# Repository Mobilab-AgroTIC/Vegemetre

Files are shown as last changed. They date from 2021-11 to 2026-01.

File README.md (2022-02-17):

# Vegemetre

Le vegemetre permet de mesurer un indice tel que le NDVI pour observer l'expression photosynthétique des plantes. Il mesure 18 longueurs d'ondes allant de 350nm à 950nm. 
Toutes les données sont stockées sur une carte SD.

Ce repository contient

    le code Arduino
    un tutoriel d'utilisation du boitier

# Liste du matériel 
- Un [Arduino Uno Rev 3](https://www.amazon.fr/Arduino-A000066-M%C3%A9moire-flash-32/dp/B008GRTSV6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)
- Un [cable USB type B](https://www.amazon.fr/MYAMIA-Alimentation-Transmission-Donn%C3%A9es-Arduino/dp/B07H23N214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) parfois inclu avec l'arduino
- Un shield LCD comme le [VMA203](https://www.velleman.eu/products/view/?country=be&lang=fr&id=435510)
- Un capteur [AS7265x](https://www.sparkfun.com/products/15050)
- La connectique pour connecter le capteur : 
    - Un [cable qwiic](https://www.sparkfun.com/products/14427)
    - Un [shield qwiic](https://www.sparkfun.com/products/14352)
- Un lecteur de carte SD du type [AZDelivery](https://www.amazon.fr/azdelivery-Reader-M%C3%A9moire-Memory-Arduino/dp/B077MCR2RC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)
- Une [carte micro SD](https://www.amazon.fr/QUMOX-Micro-Carte-M%C3%A9moire-Classe/dp/B07F81QTPP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) classique (pas besoin d'une grosse carte de nouvelle génération. Les cartes de 64Go ne sont pas supportées)

# Montage du système
Le plus délicat est le soudage du support de carte SD sur le shield qwiic.
Détails à venir

# Installation du code

Un guide d'utilisation de ce capteur est donné par [Sparkfun](https://learn.sparkfun.com/tutorials/spectral-triad-as7265x-hookup-guide/all)

Il est nécessaire de télécharger [cette librairie](https://github.com/sparkfun/SparkFun_AS7265x_Arduino_Library/archive/main.zip) pour faire fonctionner le capteur. Telecharger le zip, puis dans le logiciel Arduino, cliquez sur *Croquis > Inclure une bibliothèque > Ajouter la bibliothèque ZIP*, puis selectionner le .zip téléchargé


Le code est disponible sur ce github. Il faut le flasher sur la carte : après avoir branché l'arduino, il faut aller dans *Outils > ports >* Choisir l'arduino
puis cliquer sur le bouton *téléverser* :



#Utilisation du végémetre
La notice d'utilisation est à la racine du github

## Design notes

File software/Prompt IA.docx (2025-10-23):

Fais moi un code pour une arduino UNO, branché avec :

- Un shield LCD de DFROBOT
- Une SD card reader (branché en CS=2)
- Un capteur AS7265x, branché en I2C. Il prend 18 longueurs d’ondes :

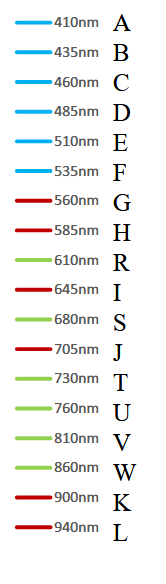
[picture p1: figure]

Le principe est de faire l’acquisition de données spectrales avec le capteur. On veut les stocker sur carte SD.

Quand on allume l’Arduino :

1. On Affiche au milieu « Vegemetre » puis sur la ligne du bas « AgroTIC »
2. On vérifie qu’on a bien le capteur, qu’il répond. Si oui, on envoie Capteur OK (sinon, Capteur KO)
3. Si le capteur est OK, on vérifie qu’on peut bien lire la carte SD. Si non, on envoie « SD Absente. Select=continue ».
4. Si la carte SD est détéctée, on arrive sur un écran où on peut choisir la date au format MM/JJ. Un curseur permet de savoir quel champ on modifie (les 2 M et les 2J). Le 1er M ne peut etre que 0 ou 1. Le 1er J ne peut etre que 0, 1, 2, 3. En appuyant sur select, un fichier MM-JJ.txt est créé avec l’entete :
  a. ID,TempC,LED,NDVI,410nm-A,435nm-B,460nm-C,485nm-D,510nm-E,535nm-F,560nm-G,585nm-H,610nm-R,645nm-I,680nm-S,705nm-J,730nm-T,760nm-U,810nm-V,860nm-W,900nm-K,940nm-L
5. Après le choix du fichier, (ou bien si on a cliqué sur « select=continue » car pas de carte SD, cf point 3) on peut choisir un mode « ponctuel » ou « auto ».
  a. Le mode ponctuel permet de faire de l’acquisition en appuyant sur un bouton Right, et Select pour le sauver (sauf si la carte SD est absente et qu’on avait cliqué au début sur Select=continue, cf point 3)
  b. Le mode auto amène à un autre menu où on peut choisir l’intervalle en secondes entre 2 acquisitions.
6. On arrive sur l’écran «principal » où on peut voir « Id : 00 » en haut à gauche. Cet Id s’incrémente dès qu’une donnée est enregistrée dans la carte SD. Cela permet de ne pas s’y perdre dans le jeu de données.
7. En mode Ponctuel,
  a. en appuyant sur « Right », une acqusition est prise. On extrait les valeurs pour calculer et afficher un NDVI :

float NDVI = (

((sensor.getCalibratedU()+sensor.getCalibratedV()+sensor.getCalibratedW()) - (sensor.getCalibratedS()+sensor.getCalibratedJ()+sensor.getCalibratedI()))

/

((sensor.getCalibratedU()+sensor.getCalibratedV()+sensor.getCalibratedW()) + (sensor.getCalibratedS()+sensor.getCalibratedJ()+sensor.getCalibratedI()))

);

  b. en appuyant sur « LEFT », on active ou desactive les LED Flash du capteur pour la prochaine acquisition
  c. En appuyant sur Up ou Down, on fait +1 ou -1 à l’Id.
  d. En appuyant sur SELECT, on sauvegarde les données dans la carte SD et on incrémente l’ID de +1 pour la prochaine mesure.
8. En mode Auto
  a. En appuyant sur Select, on lance l’enregistrement (un petit indicateur le montre sur l’écran). Le NDVI est affiché à chaque acquisition. La donnée est sauvegardée dans la carte SD en fonction de l’intervalle de temps définie. A chaque donnée sauvegardée, on incrémente l’ID de +1 pour la prochaine mesure.
  b. En appuyant sur « LEFT », on active ou desactive les LED Flash du capteur pour la prochaine acqusisiton. Cela peut être modifié en cours de mesure, pour la prochaine acquisition.

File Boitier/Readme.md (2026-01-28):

Boitier modélisé sur Fusion 360 avec deux types de couvercles. Un couvercle pour les shield ldc qui ont des petits boutons poussoirs et un autre pour les grands boutons poussoirs.

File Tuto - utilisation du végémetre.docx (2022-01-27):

# Utilisation du Végémetre

Au démarrage de l’appareil, l’appareil peut afficher 2 messages d’erreurs :

- SD failed : La carte SD n’est pas reconnue ou mal insérée
- Sensor failed : le capteur n’est pas reconnu. Il suffit de bien vérifier la connexion du capteur.

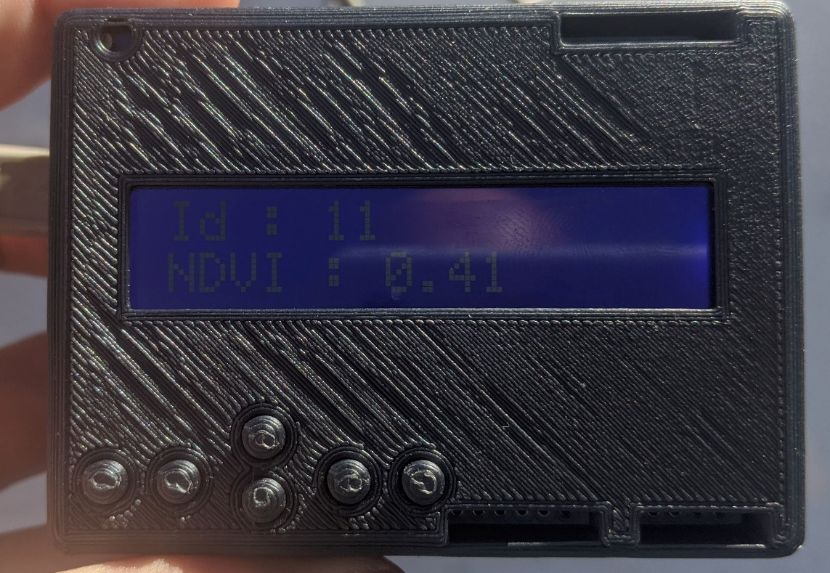
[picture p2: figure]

Si tout se passe bien, la date est demandée.

Rst

Haut

Bas

->

<-

Sel.

## Parametrage de la date

La date sert uniquement à nommer le fichier dans lequel les données seront stockées. Le format demandé est JJ/MM

Il suffit de déplacer le curseur avec les touches « <- » et « -> »

Pour choisir le chiffre, Appuyer sur les touches « Haut » ou « Bas »

Une fois la date sélectionnée, appuyer sur le bouton « Sel. »

Le bouton « Rst » ou Reset redémarre l’appareil.

# Prise des mesures

## Changer l’ID

L’identifiant est affiché à l’écran. Par défaut, il est positionné sur 0. Il est possible de le changer en appuyant sur les touches « Haut » ou « Bas ».

## Prendre une mesure

Pour prendre une mesure, il faut appuyer sur le bouton « -> ». Le NDVI s’affiché, mesuré avec les longueurs d’ondes acquises. A ce stade, les valeurs ne sont pas stockées sur la carte SD.

## Enregistrer la mesure

Si cela convient à l’opérateur, il peut enregistrer la valeur sur la carte SD en appuyant sur le bouton « Sel. ». Sinon, il peut reprendre une valeur en appuyant sur « -> ». Tant que la touche « Sel. » n’est pas appuyée, aucune valeur n’est stockée.

Lorsque la valeur est enregistrée, l’ID augmente de 1 et l’appareil est prêt à reprendre une mesure.

## Activer les LED

Il est possible d’activer les LED du capteur en appuyant sur le bouton « <- ». un « LUX » apparait à l’écran dans ce cas.

# Format de stockage des données

Les données stockées sur le fichier JJ_MM.txt sont :

- ID : L’identifiant de la mesure
- BULB : si la lumière était actionnée ou non
- TEMP : la température du capteur au moment de l’acquisition
- calXXX : La donnée de reflectance calibrée par rapport à la température, à la longueur d’onde XXX.

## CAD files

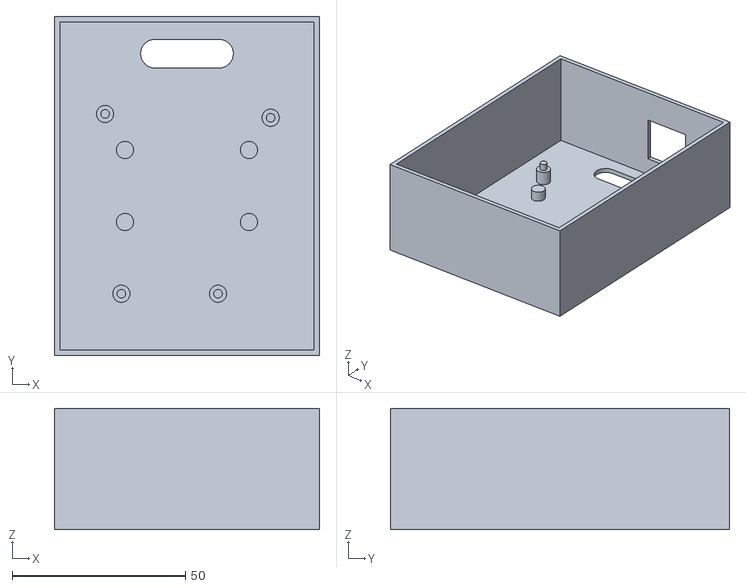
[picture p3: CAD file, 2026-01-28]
Boitier/vegemetre_boitier.stl
76.5 x 98.0 x 35.0

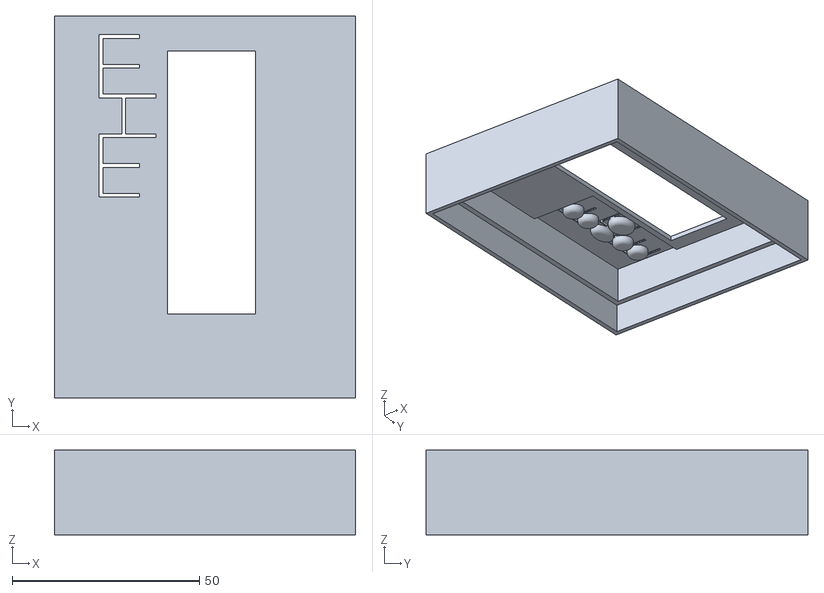
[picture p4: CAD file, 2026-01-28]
Boitier/vegemetre_couvercle_grands_boutons.stl
80.3 x 101.8 x 22.6

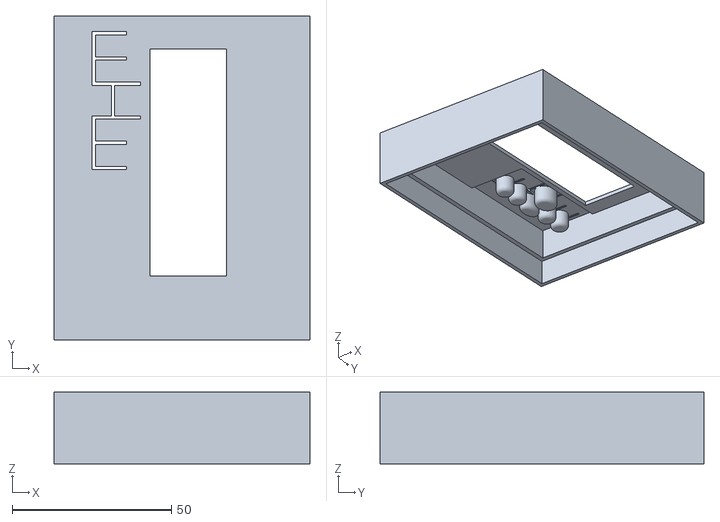
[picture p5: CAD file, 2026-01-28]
Boitier/vegemetre_couvercle_petits_boutons.stl
80.3 x 101.8 x 22.6

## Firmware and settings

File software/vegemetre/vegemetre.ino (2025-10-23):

/*
  Vegemetre - Arduino UNO
  Hardware:
    - DFROBOT LCD Keypad Shield (LCD: RS=8, E=9, D4..D7=4,5,6,7; Keys on A0)
    - SD card reader on CS = 2 (SPI on 11/12/13). Keep pin 10 OUTPUT to stay SPI master.
    - SparkFun AS7265x spectral sensor on I2C (A4=SDA, A5=SCL)

  Notes (v2 fixes):
    - Avoid Arduino String to prevent SRAM fragmentation → use C buffers/prints.
    - Backlight control on pin 10 for visual feedback (flash on save/acq). Pin 10 must remain OUTPUT.
    - UI: show " LED" only when ON (nothing if OFF) to fit 16 cols.
    - Safer SD writes using f.print() chunks instead of a big snprintf.

  Features:
    - Splash screen "Vegemetre" / "AgroTIC"
    - Check sensor, then SD (optional continue without SD)
    - Date selector MM/JJ; creates file MM-JJ.txt with CSV header
    - Modes: Ponctuel / Auto (interval in seconds)
    - NDVI from U,V,W (NIR) and S,J,I (red)
*/

#include <Wire.h>
#include <LiquidCrystal.h>
#include <SPI.h>
#include <SD.h>
#include <string.h>
#include "SparkFun_AS7265X.h"

// ===================== Data types =====================
struct DateMMJJ { uint8_t MM; uint8_t JJ; };

struct SpecData {
  float A,B,C,D,E,F,G,H,R,I,S,J,T,U,V,W,K,L; // 18 channels
};

// ===================== Prototypes =====================
int    readLCDButtons();
int    waitButtonPress(uint16_t releaseDelay = 120);
void   lcdClear();
void   printCentered(uint8_t row, const char* msg);
void   splash();
void   messageTwoLines(const char* l1, const char* l2);
void   drawDateScreen(const DateMMJJ& d, uint8_t cursorIdx);
void   makeFilename(const DateMMJJ& d, char out[16]);
void   writeCsvHeader(File &f);
bool   doAcquisition(SpecData &d, bool useBulb);
float  computeNDVI(const SpecData &d);
void   writeCsvLine(File &f, int id, float tempC, bool led, float ndvi, const SpecData &d);
void   showMainScreen();
void   showAutoIntervalScreen(uint16_t value);
void   showModeSelect();
void   backlightOn();
void   backlightOff();
void   flashBacklight(uint8_t blinks = 1, uint16_t onMs = 60, uint16_t offMs = 60);

// ================= Pins =================
LiquidCrystal lcd(8, 9, 4, 5, 6, 7);
AS7265X sensor;

const uint8_t SD_CS = 2;
const uint8_t BACKLIGHT_PIN = 10; // DFRobot Shield backlight (also SS). Must stay OUTPUT.

// ================= App state =================
bool sdOK = false;
char filename[16] = {0};
int    ID = 0;
bool   bulbOn = false;      // illumination LED state for next acquisition
float  lastNDVI = NAN;
float  lastTempC = NAN;

// Modes
enum AcqMode { MODE_PONCTUEL = 0, MODE_AUTO = 1 };
AcqMode mode = MODE_PONCTUEL;

// Auto
uint16_t intervalSec = 5;           // user-selected interval
unsigned long lastAutoMs = 0;       // last acquisition timestamp
bool autoRunning = false;           // recording flag in auto mode
unsigned long noSaveUntilMs = 0;     // guard window to avoid unintended save after key events

// ================= Buttons (DFROBOT shield) =================
#define BTN_RIGHT  0
#define BTN_UP     1
#define BTN_DOWN   2
#define BTN_LEFT   3
#define BTN_SELECT 4
#define BTN_NONE   5

int readLCDButtons() {
  int adc = analogRead(A0);
  if (adc > 1000) return BTN_NONE;
  if (adc <  50) return BTN_RIGHT;
  if (adc < 250) return BTN_UP;
  if (adc < 450) return BTN_DOWN;
  if (adc < 650) return BTN_LEFT;
  if (adc < 850) return BTN_SELECT;
  return BTN_NONE;
}

int waitButtonPress(uint16_t releaseDelay) {
  int b;
  do { b = readLCDButtons(); } while (b == BTN_NONE);
  delay(releaseDelay);
  while (readLCDButtons() != BTN_NONE) { delay(5); }
  return b;
}

// ================ Backlight ================
void backlightOn(){ digitalWrite(BACKLIGHT_PIN, HIGH); }
void backlightOff(){ digitalWrite(BACKLIGHT_PIN, LOW); }
void flashBacklight(uint8_t blinks, uint16_t onMs, uint16_t offMs){
  for(uint8_t i=0;i<blinks;i++){ backlightOff(); delay(offMs); backlightOn(); delay(onMs); }
}

// ================ UI helpers ==================
void lcdClear() { lcd.clear(); lcd.setCursor(0,0); }

void printCentered(uint8_t row, const char* msg) {
  uint8_t len = (uint8_t)strlen(msg);
  int8_t col = (16 - (int8_t)len) / 2; if (col < 0) col = 0;
  lcd.setCursor(col, row); lcd.print(msg);
}

void splash() {
  lcdClear();
  printCentered(0, "Vegemetre");
  printCentered(1, "AgroTIC");
  flashBacklight(2, 90, 90); // petit feedback visuel
}

void messageTwoLines(const char* l1, const char* l2) {
  lcdClear();
  lcd.setCursor(0,0); lcd.print(l1);
  lcd.setCursor(0,1); lcd.print(l2);
}

// ================ Date selection & file ==================
void drawDateScreen(const DateMMJJ& d, uint8_t cursorIdx) {
  lcdClear();
  printCentered(0, "Choix date MM/JJ");
  // fixed columns: 3,4,'/',6,7
  lcd.setCursor(3,1); lcd.print((d.MM/10)%10);
  lcd.setCursor(4,1); lcd.print(d.MM%10);
  lcd.setCursor(5,1); lcd.print('/');
  lcd.setCursor(6,1); lcd.print((d.JJ/10)%10);
  lcd.setCursor(7,1); lcd.print(d.JJ%10);
  uint8_t col = (cursorIdx==0)?3:(cursorIdx==1)?4:(cursorIdx==2)?6:7;
  lcd.setCursor(col,0); lcd.print('^');
}

void makeFilename(const DateMMJJ& d, char out[16]) {
  snprintf(out, 16, "%02u-%02u.txt", d.MM, d.JJ);
}

void writeCsvHeader(File &f) {
  f.println(F("ID,TempC,LED,NDVI,410nm-A,435nm-B,460nm-C,485nm-D,510nm-E,535nm-F,560nm-G,585nm-H,610nm-R,645nm-I,680nm-S,705nm-J,730nm-T,760nm-U,810nm-V,860nm-W,900nm-K,940nm-L"));
}

// ================ Sensor acquisition ==================
bool doAcquisition(SpecData &d, bool useBulb) {
  if (useBulb) sensor.takeMeasurementsWithBulb();
  else         sensor.takeMeasurements();

  d.A = sensor.getCalibratedA(); d.B = sensor.getCalibratedB(); d.C = sensor.getCalibratedC(); d.D = sensor.getCalibratedD();
  d.E = sensor.getCalibratedE(); d.F = sensor.getCalibratedF(); d.G = sensor.getCalibratedG(); d.H = sensor.getCalibratedH();
  d.R = sensor.getCalibratedR(); d.I = sensor.getCalibratedI(); d.S = sensor.getCalibratedS(); d.J = sensor.getCalibratedJ();
  d.T = sensor.getCalibratedT(); d.U = sensor.getCalibratedU(); d.V = sensor.getCalibratedV(); d.W = sensor.getCalibratedW();
  d.K = sensor.getCalibratedK(); d.L = sensor.getCalibratedL();
  return true;
}

float computeNDVI(const SpecData &d) {
  float nir = d.U + d.V + d.W;      // U(760) + V(810) + W(860)
  float red = d.S + d.J + d.I;      // S(680) + J(705) + I(645)
  float denom = nir + red;
  if (denom == 0) return NAN;
  return (nir - red) / denom;
}

void writeCsvLine(File &f, int id, float tempC, bool led, float ndvi, const SpecData &d) {
  f.print(id); f.print(',');
  f.print(tempC, 2); f.print(',');
  f.print(led?1:0); f.print(',');
  f.print(ndvi, 5); f.print(',');
  f.print(d.A,5); f.print(','); f.print(d.B,5); f.print(','); f.print(d.C,5); f.print(','); f.print(d.D,5); f.print(',');
  f.print(d.E,5); f.print(','); f.print(d.F,5); f.print(','); f.print(d.G,5); f.print(','); f.print(d.H,5); f.print(',');
  f.print(d.R,5); f.print(','); f.print(d.I,5); f.print(','); f.print(d.S,5); f.print(','); f.print(d.J,5); f.print(',');
  f.print(d.T,5); f.print(','); f.print(d.U,5); f.print(','); f.print(d.V,5); f.print(','); f.print(d.W,5); f.print(',');
  f.print(d.K,5); f.print(','); f.println(d.L,5);
}

// ================ Screens ==================
void showMainScreen() {
  lcdClear();
  // Line 0: "Id:xx  M:P/A [ LED]"
  lcd.setCursor(0,0);
  lcd.print(F("Id:")); if (ID<10) lcd.print('0'); lcd.print(ID);
  lcd.print(F("  M:")); lcd.print(mode==MODE_PONCTUEL? 'P':'A');
  if (bulbOn) lcd.print(F("  LED")); // rien si OFF

  // Line 1: "NDVI: x.xxx  "+ REC if auto
  lcd.setCursor(0,1);
  lcd.print(F("NDVI:"));
  if (isnan(lastNDVI)) { lcd.print(F(" ---")); }
  else { lcd.print(' '); lcd.print(lastNDVI,3); }
  if (autoRunning) { lcd.print(F("  REC")); }
}

void showAutoIntervalScreen(uint16_t value) {
  lcdClear();
  lcd.print(F("Intervalle (s):"));
  lcd.setCursor(0,1); lcd.print(value);
  lcd.print(F("  Up/Down Sel=OK"));
}

void showModeSelect() {
  lcdClear();
  lcd.print(F("Mode: Up=Ponc Down=Auto"));
  lcd.setCursor(0,1); lcd.print(F("Select=valider"));
}

// ================ Setup ==================
void setup() {
  pinMode(BACKLIGHT_PIN, OUTPUT); // pin 10
  backlightOn();                  // backlight ON by default

  lcd.begin(16,2);
  splash();

  Wire.begin();
  delay(50);
  bool sensorOK = sensor.begin();
  delay(20);
  if (sensorOK) messageTwoLines("Capteur OK", "");
  else          messageTwoLines("Capteur KO", "Verif. cablage");
  flashBacklight(1);
  delay(600);

  if (sensorOK) {
    if (SD.begin(SD_CS)) { sdOK = true; messageTwoLines("SD OK", ""); }
    else { sdOK = false; messageTwoLines("SD absente.", "Select=continue"); waitButtonPress(); }
    flashBacklight(1);
    delay(400);
  }

  if (sensorOK && sdOK) {
    DateMMJJ d = { .MM = 1, .JJ = 1 };
    uint8_t cursor = 0;
    while (true) {
      drawDateScreen(d, cursor);
      int b = waitButtonPress();
      if (b == BTN_LEFT) { if (cursor>0) cursor--; }
      else if (b == BTN_RIGHT) { if (cursor<3) cursor++; }
      else if (b == BTN_UP)    {
        // Edit digit-by-digit with locked tens ranges
        if (cursor == 0) { // Month tens: 0 or 1
          uint8_t tens = d.MM / 10; tens = (tens==0)?1:0; // toggle 0<->1
          uint8_t units = d.MM % 10;
          if (tens == 0) { if (units==0) units = 1; }   // months 01..09
          else { if (units>2) units = 2; }              // months 10..12
          d.MM = tens*10 + units;
        } else if (cursor == 1) { // Month units
          uint8_t tens = d.MM / 10; uint8_t units = d.MM % 10;
          if (tens==0) { units++; if (units>9) units=1; } // 1..9
          else { units++; if (units>2) units=0; }         // 0..2
          d.MM = tens*10 + units;
        } else if (cursor == 2) { // Day tens: 0..3
          uint8_t tens = d.JJ / 10; tens = (tens+1); if (tens>3) tens=0;
          uint8_t units = d.JJ % 10;
          if (tens==0) { if (units==0) units=1; }       // 01..09
          else if (tens==3) { if (units>1) units=1; }   // 30..31
          d.JJ = tens*10 + units;
        } else { // Day units
          uint8_t tens = d.JJ / 10; uint8_t units = d.JJ % 10;
          if (tens==0) { units++; if (units>9) units=1; } // 1..9
          else if (tens==3) { units++; if (units>1) units=0; } // 0..1
          else { units++; if (units>9) units=0; } // 10..29
          d.JJ = tens*10 + units;
        }
      }
      else if (b == BTN_DOWN)  {
        if (cursor == 0) { // Month tens: 0 or 1
          uint8_t tens = d.MM / 10; tens = (tens==0)?1:0; // toggle 0<->1
          uint8_t units = d.MM % 10;
          if (tens == 0) { if (units==0) units = 1; } else { if (units>2) units = 2; }
          d.MM = tens*10 + units;
        } else if (cursor == 1) { // Month units
          uint8_t tens = d.MM / 10; uint8_t units = d.MM % 10;
          if (tens==0) { if (units==1) units=9; else units--; }
          else { if (units==0) units=2; else units--; }
          d.MM = tens*10 + units;
        } else if (cursor == 2) { // Day tens 0..3
          uint8_t tens = d.JJ / 10; tens = (tens==0)?3:(uint8_t)(tens-1);
          uint8_t units = d.JJ % 10;
          if (tens==0) { if (units==0) units=1; } else if (tens==3) { if (units>1) units=1; }
          d.JJ = tens*10 + units;
        } else { // Day units
          uint8_t tens = d.JJ / 10; uint8_t units = d.JJ % 10;
          if (tens==0) { if (units==1) units=9; else units--; }
          else if (tens==3) { if (units==0) units=1; else units--; }
          else { if (units==0) units=9; else units--; }
          d.JJ = tens*10 + units;
        }
      }
      else if (b == BTN_SELECT) {
        makeFilename(d, filename);
        File f = SD.open(filename, FILE_WRITE);
        if (!f) { messageTwoLines("Err. creation", filename); delay(1200); }
        else { writeCsvHeader(f); f.flush(); f.close(); break; }
      }
    }
  }

  // Mode selection
  lcdClear();
  lcd.print(F("Up=Ponc  Down=Auto"));
  lcd.setCursor(0,1); lcd.print(F("Select=valider"));
  mode = MODE_PONCTUEL;
  while (true) {
    int b = waitButtonPress();
    if (b == BTN_UP) mode = MODE_PONCTUEL;
    else if (b == BTN_DOWN) mode = MODE_AUTO;
    else if (b == BTN_SELECT) break;
    lcd.setCursor(0,1);
    lcd.print(F("Mode:")); lcd.print(mode==MODE_PONCTUEL?"Ponctuel  ":"Auto      ");
  }

  if (mode == MODE_AUTO) {
    uint16_t val = intervalSec;
    while (true) {
      showAutoIntervalScreen(val);
      int b = waitButtonPress();
      if (b == BTN_UP)   { if (val < 3600) val++; }
      else if (b == BTN_DOWN) { if (val > 1) val--; }
      else if (b == BTN_SELECT) { intervalSec = val; break; }
    }
  }

  showMainScreen();
}

// ================ Loop ==================
void loop() {
  // Auto mode timing
  if (mode == MODE_AUTO && autoRunning) {
    unsigned long now = millis();
    unsigned long intervalMs = (unsigned long)intervalSec * 1000UL;
    if (now >= noSaveUntilMs && (now - lastAutoMs) >= intervalMs) {
      lastAutoMs = now;
      SpecData d; if (doAcquisition(d, bulbOn)) {
        lastNDVI = computeNDVI(d);
        lastTempC = sensor.getTemperature();
        showMainScreen();
        if (sdOK && filename[0]) {
          File f = SD.open(filename, FILE_WRITE);
          if (f) {
            writeCsvLine(f, ID, lastTempC, bulbOn, lastNDVI, d);
            f.flush(); f.close();
            ID++; flashBacklight(1);
          }
        }
      } else {
        messageTwoLines("Acq. echouee", ""); flashBacklight(2,50,50); delay(400);
      }
    }
  }

  // Buttons
  int b = readLCDButtons();
  if (b == BTN_NONE) return;
  delay(120);
  while (readLCDButtons() != BTN_NONE) { delay(5); }

  if (mode == MODE_PONCTUEL) {
    if (b == BTN_RIGHT) {
      SpecData d; if (doAcquisition(d, bulbOn)) {
        lastNDVI = computeNDVI(d);
        lastTempC = sensor.getTemperature();
        flashBacklight(1);
        showMainScreen();
      } else { messageTwoLines("Acq. echouee", ""); flashBacklight(2,50,50); delay(400); }
    }
    else if (b == BTN_LEFT) { bulbOn = !bulbOn; if (autoRunning) { lastAutoMs = millis(); noSaveUntilMs = millis() + 600; } showMainScreen(); }
    else if (b == BTN_UP)   { if (ID < 99) ID++; showMainScreen(); }
    else if (b == BTN_DOWN) { if (ID > 0)  ID--; showMainScreen(); }
    else if (b == BTN_SELECT) {
      if (!sdOK) { messageTwoLines("SD absente", "Pas de sauvegarde"); flashBacklight(2,40,40); delay(500); showMainScreen(); return; }
      if (isnan(lastNDVI)) { messageTwoLines("Rien a sauver", "Faites RIGHT avant"); flashBacklight(2,40,40); delay(600); showMainScreen(); return; }
      File f = SD.open(filename, FILE_WRITE);
      if (!f) { messageTwoLines("Erreur fichier", filename); flashBacklight(3,40,40); delay(600); }
      else {
        SpecData d; if (doAcquisition(d, bulbOn)) {
          float nd = computeNDVI(d);
          float tc = sensor.getTemperature();
          writeCsvLine(f, ID, tc, bulbOn, nd, d);
          f.flush(); f.close();
          ID++; lastNDVI = nd; lastTempC = tc; flashBacklight(1);
          showMainScreen();
        } else { f.close(); messageTwoLines("Acq. echouee", ""); flashBacklight(2,50,50); delay(500); }
      }
    }
  } else { // MODE_AUTO
    if (b == BTN_SELECT) { autoRunning = !autoRunning; if (autoRunning) { lastAutoMs = millis(); noSaveUntilMs = millis() + 600; } flashBacklight(1); showMainScreen(); }
    else if (b == BTN_LEFT) { bulbOn = !bulbOn; showMainScreen(); }
    else if (b == BTN_UP)   { if (!autoRunning && ID < 99) ID++; showMainScreen(); }
    else if (b == BTN_DOWN) { if (!autoRunning && ID > 0)  ID--; showMainScreen(); }
    else if (b == BTN_RIGHT) {
      SpecData d; if (doAcquisition(d, bulbOn)) {
        lastNDVI = computeNDVI(d);
        lastTempC = sensor.getTemperature();
        flashBacklight(1);
        showMainScreen();
      }
    }
  }
}

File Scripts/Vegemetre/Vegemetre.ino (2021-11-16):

#include <LiquidCrystal.h>
#include "SparkFun_AS7265X.h" //Click here to get the library: http://librarymanager/All#SparkFun_AS7265X
#include <SPI.h>
#include <SD.h>


// Declare Objects
LiquidCrystal lcd(8, 9, 4, 5, 6, 7);
AS7265X sensor;
File myFile;

// define some values used by the panel and buttons
int lcd_key     = 0;
int adc_key_in  = 0;
#define btnRIGHT  0
#define btnUP     1
#define btnDOWN   2
#define btnLEFT   3
#define btnSELECT 4
#define btnNONE   5
int J = 0;
int JJ = 0;
int M = 0;
int MM = 0;
String day = "00";
String month = "00";

int ID=0;
bool bulb;
float temp;
int read_LCD_buttons()
{
 adc_key_in = analogRead(0);      // read the value from the sensor 
 if (adc_key_in > 1000) return btnNONE; // We make this the 1st option for speed reasons since it will be the most likely result
 if (adc_key_in < 50)   return btnRIGHT;  
 if (adc_key_in < 195)  return btnUP; 
 if (adc_key_in < 380)  return btnDOWN; 
 if (adc_key_in < 555)  return btnLEFT; 
 if (adc_key_in < 790)  return btnSELECT;   
 return btnNONE;  // when all others fail, return this...
}

void setup()
{
 lcd.begin(16, 2);              // start the library
 lcd.setCursor(0,0);
 lcd.print("Vegemetre"); // print a simple message
 lcd.setCursor(0,1);
 lcd.print("AGROTIC"); // print a simple message
 lcd.clear();
 
 if(sensor.begin() == false)
  {
    lcd.clear();
    lcd.print("Sensor failed!");
    while(1);
  }
}
void loop()
{
 delay(100);
   lcd.setCursor(0,0);
   lcd.print("Id : " + String(ID) + "  ");
   if (bulb ==1) {
    lcd.setCursor(11,0);
    lcd.print("LUX");
   }

   lcd_key = read_LCD_buttons();  // read the buttons
  
   switch (lcd_key)               // depending on which button was pushed, we perform an action
   {
     case btnRIGHT:
       {
       lcd.setCursor(0,1);
       lcd.print("............ ");
       sensor.disableIndicator();
       temp = sensor.getTemperatureAverage();
       if (bulb ==0){
       sensor.takeMeasurements(); }
       else if (bulb ==1) {
       sensor.takeMeasurementsWithBulb();}
       sensor.enableIndicator();
       float NDVI = (
       ((sensor.getCalibratedU()+sensor.getCalibratedV()+sensor.getCalibratedW()) - (sensor.getCalibratedS()+sensor.getCalibratedJ()+sensor.getCalibratedI()))  
       /  
       ((sensor.getCalibratedU()+sensor.getCalibratedV()+sensor.getCalibratedW()) + (sensor.getCalibratedS()+sensor.getCalibratedJ()+sensor.getCalibratedI()))
       );
       lcd.setCursor(0,1);
       lcd.print("NDVI : ");
       lcd.print(NDVI,2);
       lcd.print(" ");
       break;
       }
     case btnLEFT:
       {
       lcd.setCursor(11,0);
       if (bulb == 0){
        bulb=1;
        lcd.print("LUX");
        }
       else if (bulb ==1) {
        bulb=0;
        lcd.print("   ");
  
        }
       delay(300);
       break;
       }
     case btnUP:
       {
       ID++;
       delay(200);
       break;
       }
     case btnDOWN:
       {
       if(ID>0){
       ID--;}
       delay(200);
       break;
       }
     case btnSELECT:
       {
       lcd.setCursor(0,0);
       lcd.print("Saving...");
       ID++;
       lcd.clear();
       break;
       }
       case btnNONE:
       {
       break;
       }
   }
  }
